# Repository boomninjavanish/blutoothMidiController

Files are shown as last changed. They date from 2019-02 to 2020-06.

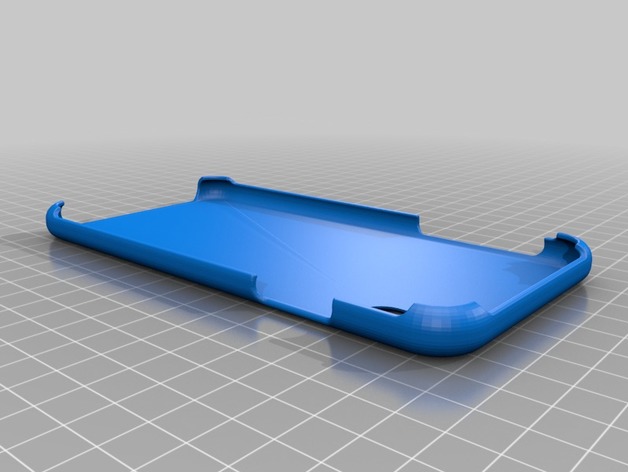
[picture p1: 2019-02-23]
case/iPhone_XS_Max_Case/images/488d43eb5ca74e51e7094f4cfa3dc460_preview_featured.jpg

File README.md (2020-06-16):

# portaMid
portaMid without phone docked

[Click to view video of portaMid in use.](https://vimeo.com/428870643)

[Click here to download the manual.](https://github.com/boomninjavanish/portaMid/raw/master/PortaMidUserManual.pdf)

The portaMid keyboard is a MIDI keyboard that works over the Bluetooth Low Energy (BLE) protocol which allows one to control music apps on any  Apple iOS device. The device contains a 500 mAh lithium polymer rechargeable battery which lasts for many hours of use. 

The one octave of piano style keys are soft to the touch but contain tactile feedback so that the user knows when the key has been pressed. Utilizing the octave  keys, the user may lower or raise the octave in which the piano-style keys play. The LED represents the octave selection via different color output.

A removable phone mount allows for use on the go for different sizes of iPhone. In fact, every iPhone since the 4S is supported by the device. Most music apps support MIDI over BLE natively and connect to the portaMid with no configuration required: just connect and use. An example of set-up with the GarageBand app may be found in the user manual.

## Motivation
I chose to create a portable MIDI controller that will allow one to dock a phone and use like a gaming controller. Often, I create music on train trips using my phone and hate inputting notes on the tiny keyboards presented on screen.

## Creation
### Board
A circuit board was designed using KiCAD and is centered around the Adafruit Feather 32u4 Bluefruit LE development microcontroller. The PCB design may be sent to a company such as OSH Park or PCB Way to be printed. The following is a bill of materials for the project (sans circuit board and case):

QTY | Part
---- | ------
1 | Adafruit Feather 32u4 Bluefruit LE Microcontroller
1 | Microchip MCP2307 I2C I/O expander (SPDIP)
1 | Adafruit NeoPixel Through-Hole 5mm LED
13 | 12mm tactile switches
3 |  5mm tactile switches
1 | 100nF ceramic capacitor
1 | 2mm DPDT surface mounted slide switch (DigiKey PN: 401-2002-1-ND)
1 | 1K SMD 1206 resistor
2 | 4.7K SMD 1206 resistor
1 | 3.7V/500mAh Lithium Ion Polymer Battery with 2-pin JST-PH connector

### Case
The final case was modeled in Fusion 360 and was designed to accept an existing phone mount that was found in [Thingiverse](https://www.thingiverse.com/thing:1313336). In order to ensure that the dimensions were correct, the board was exported from KiCAD as a STEP file. Other components such as switches, USB ports, and LEDs were imported into Fusion from a website called [GrabCAD](https://grabcad.com). This website is a community website similar to Thingiverse, but contains mostly engineering components. 

I printed the buttons in NinjaFlex 85A TPU,  which leaves the buttons tactile but feeling soft and reduces noise. The phone clamp connects to the case utilizing a ball joint which allows the keyboard to be used without the phone attached.

The side of the case contains an indentation that allows a USB micro cable to be plugged into the Adafruit feather for charging. The charging LED is visible through one hole near the port and a programmable LED is visible through another.

## User Feedback
For testing, the portaMid was given to two people for a week each. The following is the feedback from the first person:

>*I love the PortaMid!! As a musician who uses midi for all of my projects, it’s so convenient to be able to have an external midi controller. Especially because it’s so portable! I can easily fit it into my purse or backpack and use it wherever I go, train, bus, or at home. I also really love the design, the PortaMid looks as fun as it is to use. The buttons are accessible and labeled to help easily find the functions. I can’t wait to have a PortaMid of my own!*

The second person had the following to say:
>- *Good size to hold*
>- *Clear and simple user manual*
>- *LOVE the color change for different octaves- that was very useful*
>- *Bluetooth easy to set up*
>- *It only took me 10-15 min to get the hang of it and start playing melodies*
>- *I was really excited about the product, and it was more fun to use than I thought it would be*
>- *Thank you for letting me test it!*

## Improvements and Future Work
Going forward, further refinements to the device will be made. For example, it would be nice to have buttons that have the tactile feeling but are less difficult to press and create less noise. Research needs to be done on what could replace the standard tactile buttons with something that is better. In addition, it would be nice to have some velocity sensitive keys for playing more than one dynamic.

In addition, I will need to create a circuit that can poll the battery level at intervals in order to indicate the current charge level or if the battery is dying.

The stand could use a wing-nut to allow the user to adjust the tension so as to keep the unit in the proper position when in use. Also, it would allow for ease of removing the stand entirely.

While using the product, I found myself gripping the device like a game-pad. I had the thought of incorporating shoulder buttons which could be used for modulation, pitch bend, after-touch pressure, etc. 

I envision an entire line of these being made with different properties. For example it would be nice to have a version that mimics the Moog style ribbons, or another version that is a mini sequencer. It would only take finding different sensors or button layouts and incorporating them into the current design for a completely different type of interface.

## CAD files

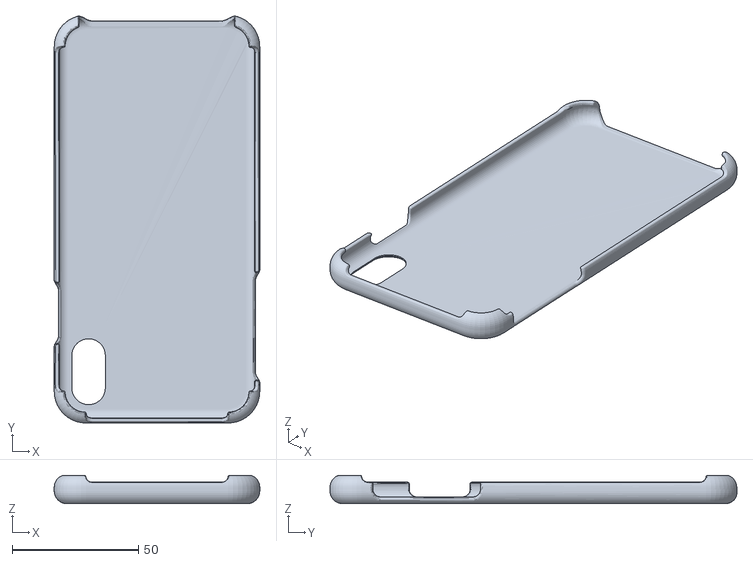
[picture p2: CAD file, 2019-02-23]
case/iPhone_XS_Max_Case/files/iphone-xs-max-case.stl
81.4 x 161.2 x 11.2

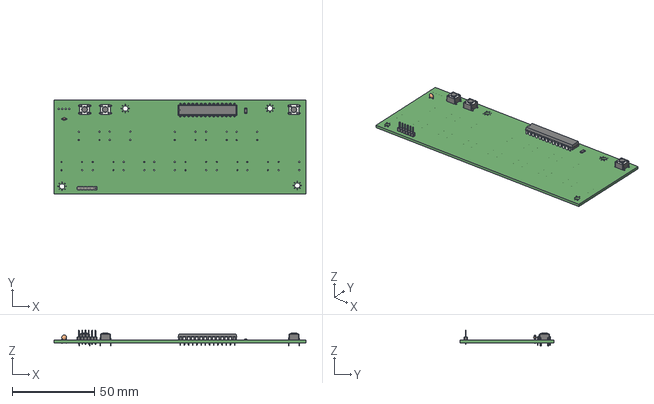
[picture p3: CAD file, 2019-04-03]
schematic/bluetoothMidiController/bluetoothMidiController.step
152.9 x 57.2 x 9.50 mm

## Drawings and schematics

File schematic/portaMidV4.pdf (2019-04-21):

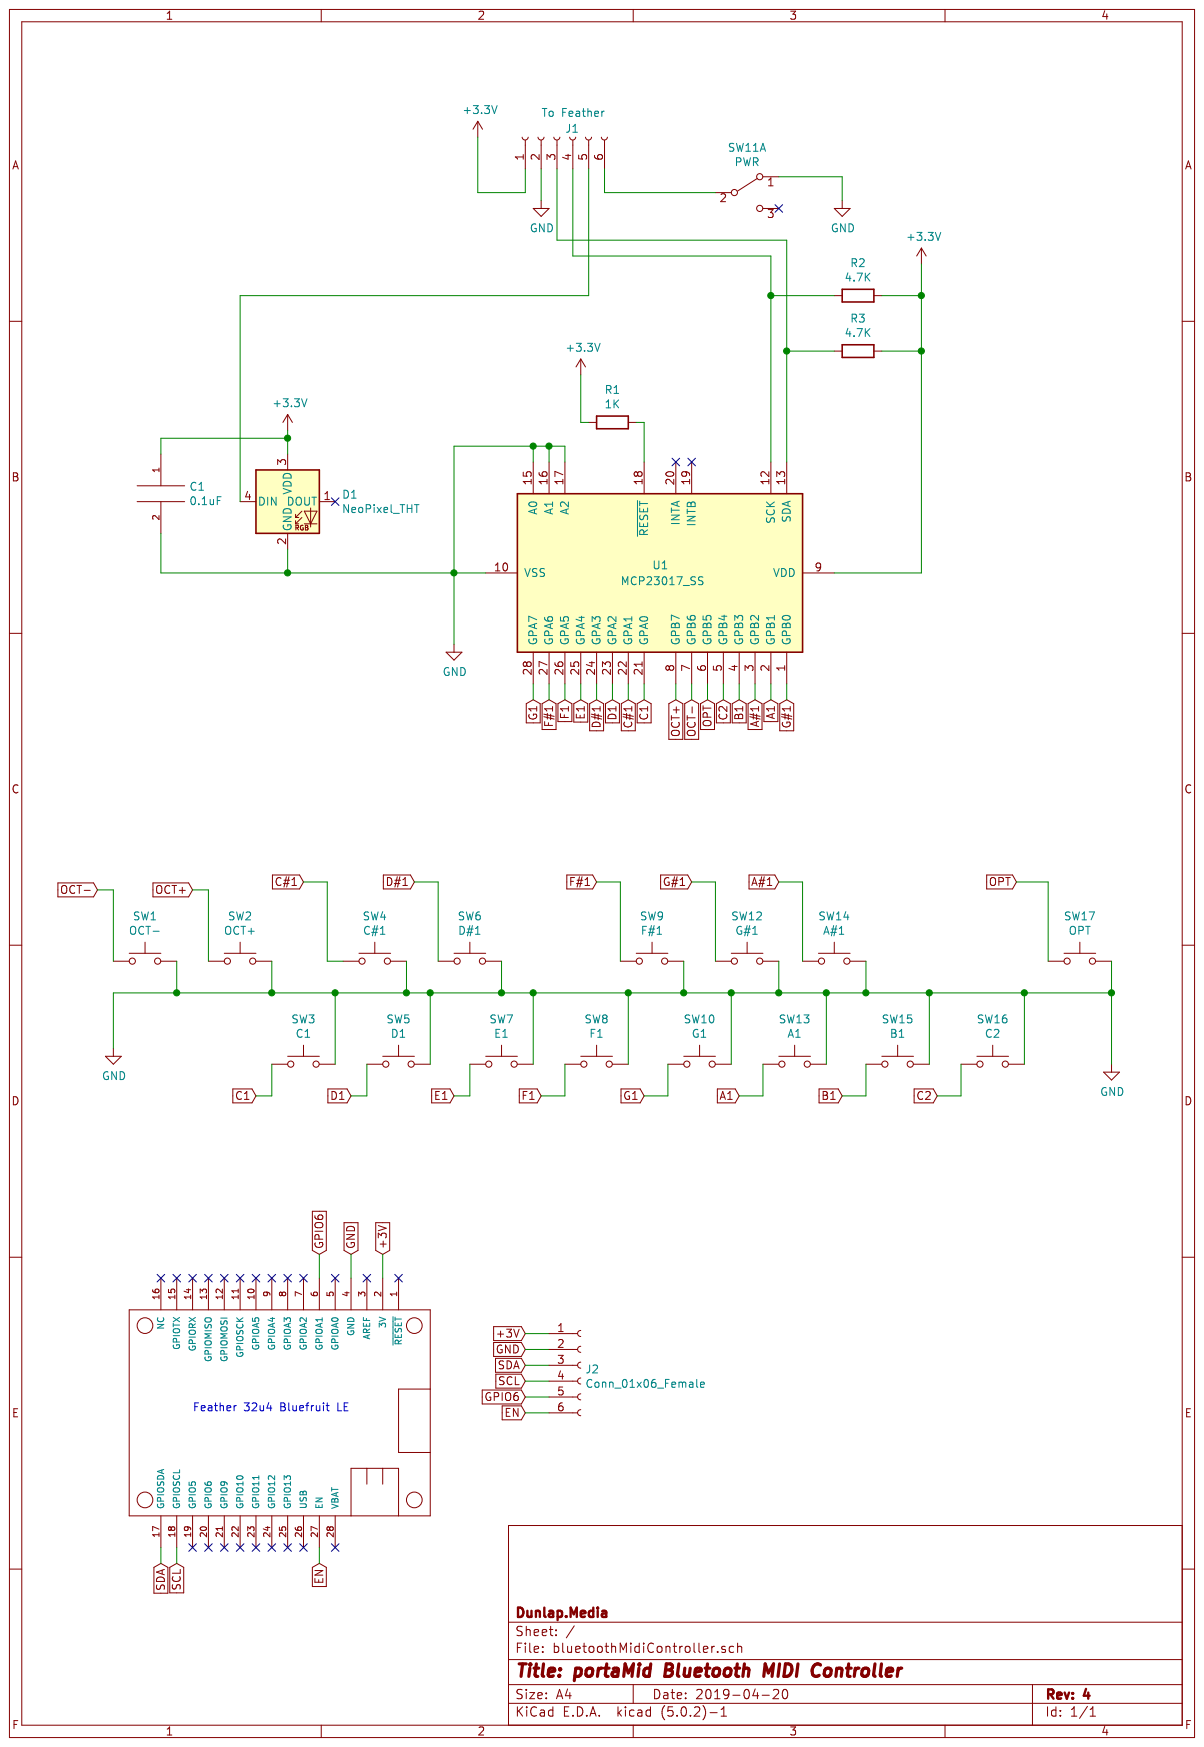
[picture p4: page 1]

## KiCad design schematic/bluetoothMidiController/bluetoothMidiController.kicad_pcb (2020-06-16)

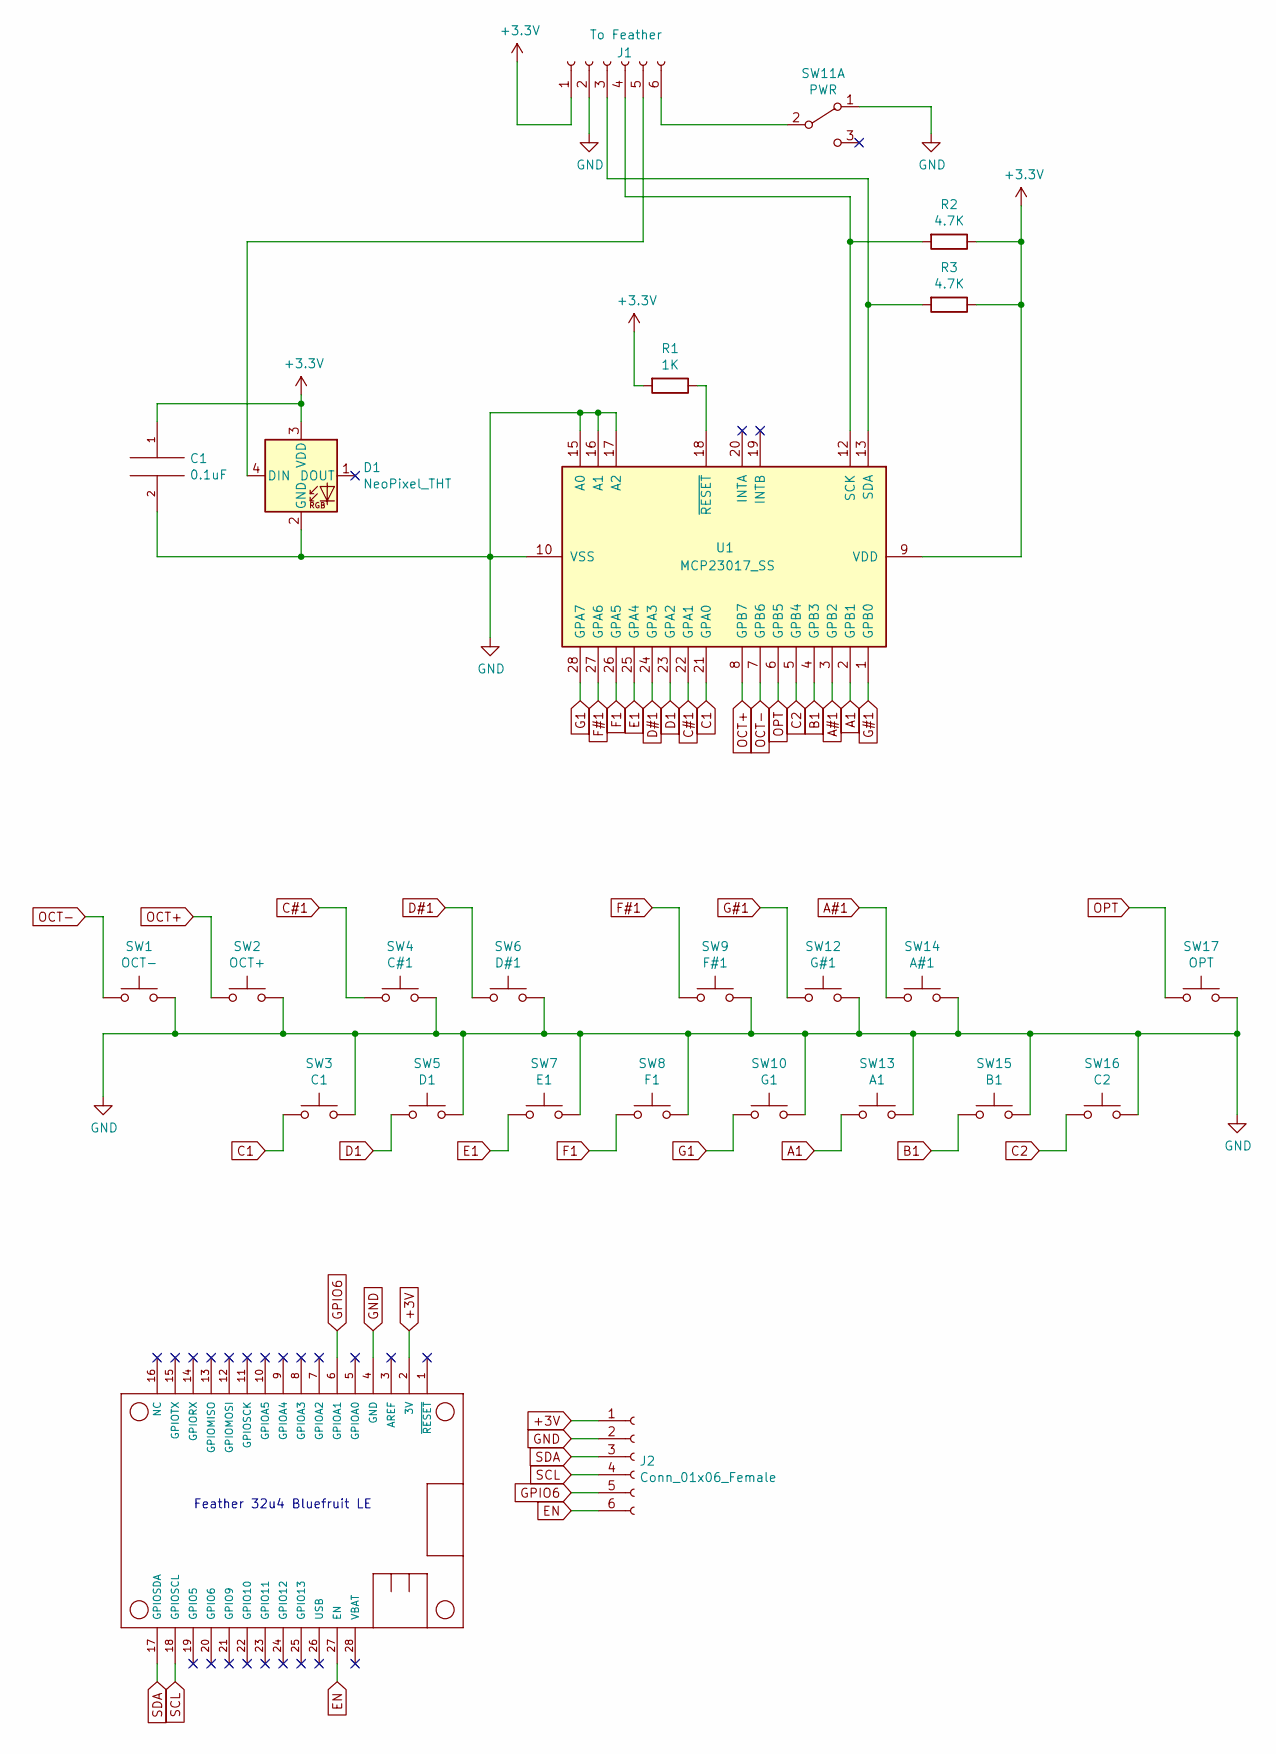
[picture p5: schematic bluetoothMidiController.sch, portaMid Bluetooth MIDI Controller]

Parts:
C1: 0.1uF; C_Disc_D3.0mm_W1.6mm_P2.50mm
D1: NeoPixel_THT; LED_D5.0mm-4_RGB_Wide_Pins
J1: To Feather; SolderWire-0.5sqmm_1x06_P4.8mm_D0.9mm_OD2.3mm
J2: Conn_01x06_Female
MS1: FEATHERWING
R1: 1K; R_1206_3216Metric_Pad1.42x1.75mm_HandSolder
R2, R3: 4.7K; R_1206_3216Metric_Pad1.42x1.75mm_HandSolder
SW1: OCT-; SW_PUSH_6mm
SW2: OCT+; SW_PUSH_6mm
SW3: C1; SW_PUSH-12mm
SW4: C#1; SW_PUSH-12mm
SW5: D1; SW_PUSH-12mm
SW6: D#1; SW_PUSH-12mm
SW7: E1; SW_PUSH-12mm
SW8: F1; SW_PUSH-12mm
SW9: F#1; SW_PUSH-12mm
SW10: G1; SW_PUSH-12mm
SW11: PWR; SW_SMD_DPDT_JS202011SCQN
SW12: G#1; SW_PUSH-12mm
SW13: A1; SW_PUSH-12mm
SW14: A#1; SW_PUSH-12mm
SW15: B1; SW_PUSH-12mm
SW16: C2; SW_PUSH-12mm
SW17: OPT; SW_PUSH_6mm
U1: MCP23017_SS; DIP-28_W7.62mm

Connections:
+3V3: C1.1, D1.3 (VDD), J1.1, R1.2, R2.1, R3.1, U1.9 (VDD)
A1: SW13.1, U1.2 (GPB1)
A#1: SW14.1, U1.3 (GPB2)
B1: SW15.1, U1.4 (GPB3)
C1: SW3.1, U1.21 (GPA0)
C2: SW16.1, U1.5 (GPB4)
C#1: SW4.1, U1.22 (GPA1)
D1: SW5.1, U1.23 (GPA2)
D#1: SW6.1, U1.24 (GPA3)
E1: SW7.1, U1.25 (GPA4)
F1: SW8.1, U1.26 (GPA5)
F#1: SW9.1, U1.27 (GPA6)
G1: SW10.1, U1.28 (GPA7)
G#1: SW12.1, U1.1 (GPB0)
GND: C1.2, D1.2 (GND), J1.2, SW1.2, SW2.2, SW3.2, SW4.2, SW5.2, SW6.2, SW7.2, SW8.2, SW9.2, SW10.2, SW11.1 (A), SW12.2, SW13.2, SW14.2, SW15.2, SW16.2, SW17.2, U1.10 (VSS), U1.15 (A0), U1.16 (A1), U1.17 (A2)
unnamed: D1.4 (DIN), J1.5
unnamed: J1.3, R3.2, U1.13 (SDA)
unnamed: J1.4, R2.2, U1.12 (SCK)
unnamed: J1.6, SW11.2 (B)
unnamed: J2.1, MS1.2 (3V)
unnamed: J2.2, MS1.4 (GND)
unnamed: J2.3, MS1.17 (GPIOSDA)
unnamed: J2.4, MS1.18 (GPIOSCL)
unnamed: J2.5, MS1.6 (GPIOA1)
unnamed: J2.6, MS1.27 (EN)
unnamed: R1.1, U1.18 (~RESET~)
OCT+: SW2.1, U1.8 (GPB7)
OCT-: SW1.1, U1.7 (GPB6)
OPT: SW17.1, U1.6 (GPB5)

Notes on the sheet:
Feather 32u4 Bluefruit LE

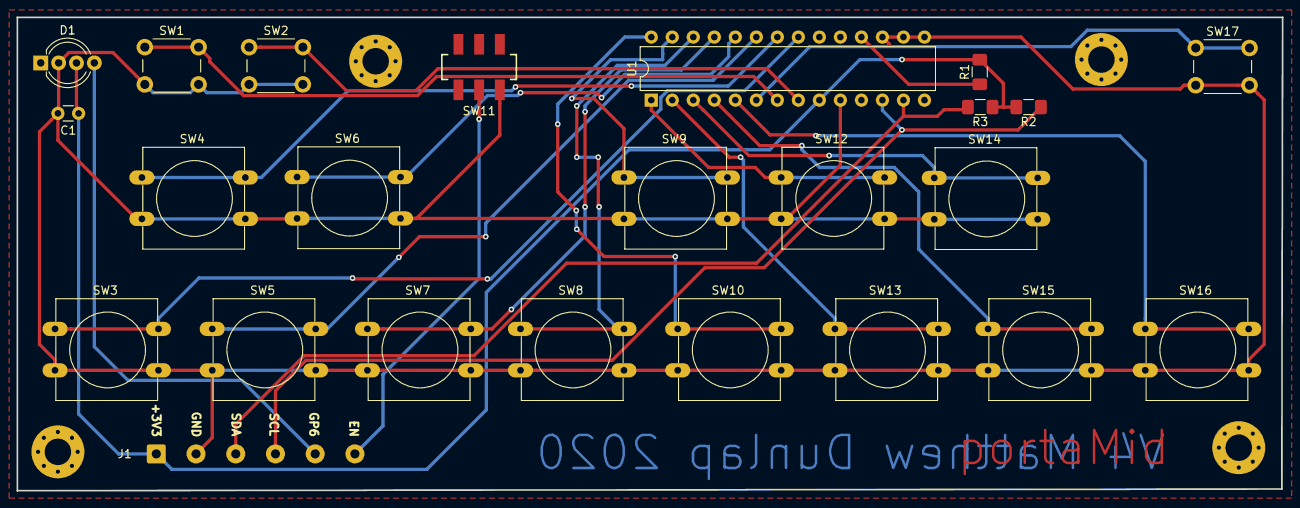
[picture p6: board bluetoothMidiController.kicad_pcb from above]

Board: 2 copper layers, 152.9 x 57.2 mm, 24 parts (0 on the bottom side), 23 nets.

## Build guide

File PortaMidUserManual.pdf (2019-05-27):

# portaMid

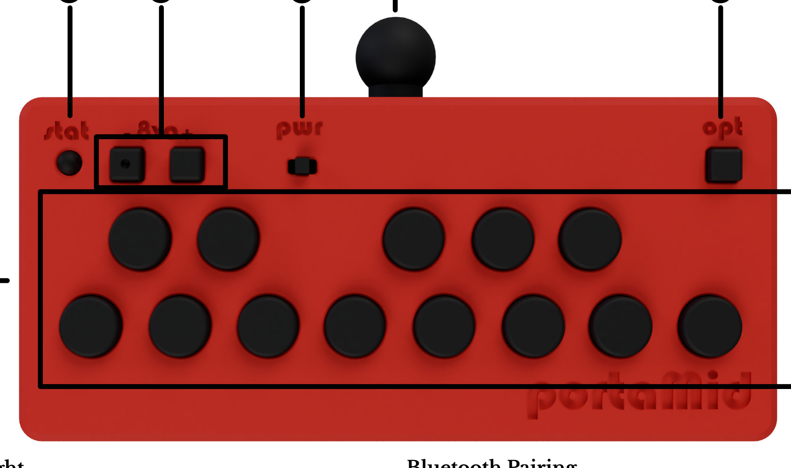
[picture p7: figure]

Status Light
Blinking Blue:
Bluetooth is ready for pairing Solid Color:
Ready for input. Color indicates which octave is selected.
No Light:
Device is turned off.
Octave Selection
Changes the octave that is played by the keyboard
Power Switch
Switches the power on the unit on or off

Phone Mount Connector
Mates with phone mounting device. Option Button
Unused at this time.
Keyboard
Press to send MIDI notes over bluetooth. USB Charging
Connect to charge device. Amber light near connector idicates that device is charging.

# User Manual

Bluetooth Pairing

When the device is first turned on, the status light will blink blue to indicate it is ready for pairing. Use the following instructions to pair with Garageband on iOS. Note that device will work on any app that supports Bluetooth MIDI on iOS and device only has to be paired each time it powered on.

1. Tap on the settings icon. (Looks like a wrench.)
2. Tap on the "Advanced" menu option.
3. Tap "Bluetooth MIDI Devices" menu option.
4. The device should appear as "portaMid" in the device list. Tap to connect.
5. Tap anywhere off of the menu to continue. Add an instrument in Garageband and enjoy. :)

### (on side)

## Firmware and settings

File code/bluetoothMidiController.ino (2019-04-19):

/*
 * bluetoothMidiController.ino
 * 2019 Matthew Dunlap
 * 
 * This project utilizes an Adafruit Feather 32u4 Bluefruit LE board (https://www.adafruit.com/product/2829)
 * to allow a user to input notes on a piano-style keyboard wirelessly to a mobile phone or tablet. 
 * Currently, as per my testing, MIDI over bluetooth LE is best supported on a device running iOS. However,
 * it is my hopes that this will change in the future.
 *
 */

#include <Arduino.h>
#include <SPI.h>
#include <SoftwareSerial.h>
#include "Adafruit_BLE.h"
#include "Adafruit_BluefruitLE_SPI.h"
#include "Adafruit_BluefruitLE_UART.h"
#include "Adafruit_BLEMIDI.h"
#include "Adafruit_MCP23017.h"
#include "BluefruitConfig.h"
#include "Bounce2mcp.h"
#include "Adafruit_NeoPixel.h"

// setup the bluetooth to only work with a certain firmware version
//  update the firmware via the Adafruit Bluefruit LE Connect app on iOS and Android
#define FACTORYRESET_ENABLE 1
#define MINIMUM_FIRMWARE_VERSION "0.7.0"

Adafruit_BluefruitLE_SPI ble(BLUEFRUIT_SPI_CS, BLUEFRUIT_SPI_IRQ, BLUEFRUIT_SPI_RST);

Adafruit_BLEMIDI midi(ble);

// define and init the MCP 23017 port expander objects
Adafruit_MCP23017 mcp;

//debouncer for the buttons
BounceMcp debouncer[16];

// track if a note is on for each button
bool buttonNoteOn[16];

// track if octave light has been turned on
bool lightOn = false;

// note and octave trackers; (OCTAVE * octaveMultiplier) + note = note in correct octave
const int OCTAVE = 12;

// track which octave we are in currently
int octaveMultiplier = 5;

// delay time in milliseconds after sending MIDI message
const int DELAY_TIME = 0;

// NeoPixel Vars
const int NEOPIXEL_PIN = 6;
Adafruit_NeoPixel pixel(1, NEOPIXEL_PIN, NEO_RGB + NEO_KHZ800);

// track milliseconds to blink led for bluetooth not connected
const long blinkInterval = 1000;
unsigned long previousMillis = 0;

// track if Bluetooth Module is connected
bool isConnected = false;


// error handeling
void error(const __FlashStringHelper*err) {
	Serial.println(err);
	while (1);
}

// when connected
void connected(void){
	isConnected = true;
	Serial.println(F(" CONNECTED!"));
	delay(1000);
}

// when disconnected
void disconnected(void){
	Serial.println("DISCONNECTED!");
	isConnected = false;
}

void setup() {
  Serial.begin(115200);

  // setup the built-in light
  pinMode(13, OUTPUT);

  // setup the neopixel
  pixel.begin();
  octaveColor(-1); // set to white
  pixel.setBrightness(10);
  pixel.show(); // initialize to brightness
  
  // setup the port expanders
  mcp.begin();
  
  /* Setup the buttons and LED
   *  
   *  All of the buttons are connected to both 23017 chips
   *    C1 - C2 are on mcp pins 0-12
   *    OCT - and + are on mcp pins 14 and 15 respectively
   *    An optional button is available on mcp pin 13
   *    The RBG LED pins are on the microcontroller: 
   *          Red = A0; Blue = A1; Green = A2
   */
  for (int i = 0; i < 16; i++){
    // initialize the button pressed tracker to false
    buttonNoteOn[i] = false;
    
    // setup pins as input
    mcp.pinMode(i, INPUT);
    mcp.pullUp(i,  HIGH);

    // setup debouncer if input
    debouncer[i] = BounceMcp();
    debouncer[i].attach(mcp, i, 5);   
  }
  
  // setup bluetooth
  if ( !ble.begin(VERBOSE_MODE) )
  {
    error(F("Couldn't find Bluefruit, make sure it's in CoMmanD mode & check wiring?"));
  }
  Serial.println( F("OK!") );

  if ( FACTORYRESET_ENABLE )
  {
    /* Perform a factory reset to make sure everything is in a known state */
    Serial.println(F("Performing a factory reset: "));
    if ( ! ble.factoryReset() ) {
      error(F("Couldn't factory reset"));
    }
    // set the Bluetooth name// set the Bluetooth name
    ble.sendCommandCheckOK("AT+GAPDEVNAME=portaMid");
  }
   ble.echo(false);

   Serial.println("Requesting Bluefruit info:");
  /* Print Bluefruit information */
  ble.info();
  
  /* Set BLE callbacks */
  ble.setConnectCallback(connected);
  ble.setDisconnectCallback(disconnected);

  Serial.println(F("Enable MIDI: "));
  if ( ! midi.begin(true) )
  {
    error(F("Could not enable MIDI"));
  }
  
  ble.verbose(false);
  
}

void loop() {

  // interval for each scanning ~ 500ms (non blocking)
  ble.update(1);

  // bail if not connected; turn light on for the first time
  if (! isConnected) {
    // blink LED blue to indicate bluetooth requires pairing
    unsigned long currentMillis = millis();

    if (currentMillis - previousMillis >= blinkInterval) {
      previousMillis = currentMillis;
      if (!lightOn){
        octaveColor(6); // turn light blue
        pixel.show();
        lightOn = true;      
      } else {
        pixel.clear();
        pixel.show();
        lightOn = false;
      }
    }
    
    
    
    return;
  } else {
    octaveColor(octaveMultiplier); // turn light on
  }
    
  
  pollButtons();

}

void pollButtons(){
  for (int i=0; i<16; i++) {  
      // calculate the current note
      int currentNote = (OCTAVE * octaveMultiplier) + i;
  
      // read the current button
      debouncer[i].update();
      
      // check if the button being pressed is an octave button
      if (i == 14 && debouncer[i].fell()){
        // lower an octave
        if (octaveMultiplier > 1) {
          octaveMultiplier -= 1;
          octaveColor(octaveMultiplier);
        }
      } else if(i == 15 && debouncer[i].fell()){
        // raise an octave
        if (octaveMultiplier < 8) {
          octaveMultiplier += 1;
          octaveColor(octaveMultiplier);
        }
      } else if( i < 14 ){ // button is piano key
        int buttonState = debouncer[i].read();
        if ( buttonState == LOW && buttonNoteOn[i] == false){  
          // send the note on 
          midi.send(0x90, currentNote, 0x64);
          buttonNoteOn[i] = true;

          digitalWrite(13, HIGH); // led on
          
          delay(DELAY_TIME);
          Serial.print("Note: ");
          Serial.println(currentNote);
        } else if (buttonState == HIGH && buttonNoteOn[i] == true) {
          // send note off
          midi.send(0x80, currentNote, 0x64);
          buttonNoteOn[i] = false;
    
          digitalWrite(13, LOW); // led off
        }
      } 
   }
}

void octaveColor(int octaveMultiplier){
  switch (octaveMultiplier){
    case 0 :
       pixel.clear(); // off
    
    case 1 :
      pixel.setPixelColor(0, 255, 0, 0); // red
      break;

    case 2 :
      pixel.setPixelColor(0, 255, 127, 0); // orange
      break;
      
    case 3 :
      pixel.setPixelColor(0, 255, 255, 0); // yellow
      break;
      
    case 4 : 
      pixel.setPixelColor(0, 0, 230, 0); // green
      break;
      
    case 5 : 
      pixel.setPixelColor(0, 0, 255, 255); // aqua
      break;

    case 6 : 
      pixel.setPixelColor(0, 0, 42, 255); // blue
      break;

    case 7 :
      pixel.setPixelColor(0, 221, 51, 255); // purple
      break;

    case 8: 
      pixel.setPixelColor(0, 255, 25, 255); // fuchsia
      break;

    default :
      pixel.setPixelColor(0, 255, 255, 255); // white
    
  }

  pixel.show();
}

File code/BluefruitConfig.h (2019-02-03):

// COMMON SETTINGS
// ----------------------------------------------------------------------------------------------
// These settings are used in both SW UART, HW UART and SPI mode
// ----------------------------------------------------------------------------------------------
#define BUFSIZE                        128   // Size of the read buffer for incoming data
#define VERBOSE_MODE                   true  // If set to 'true' enables debug output


// SOFTWARE UART SETTINGS
// ----------------------------------------------------------------------------------------------
// The following macros declare the pins that will be used for 'SW' serial.
// You should use this option if you are connecting the UART Friend to an UNO
// ----------------------------------------------------------------------------------------------
#define BLUEFRUIT_SWUART_RXD_PIN       9    // Required for software serial!
#define BLUEFRUIT_SWUART_TXD_PIN       10   // Required for software serial!
#define BLUEFRUIT_UART_CTS_PIN         11   // Required for software serial!
#define BLUEFRUIT_UART_RTS_PIN         12   // Optional, set to -1 if unused


// HARDWARE UART SETTINGS
// ----------------------------------------------------------------------------------------------
// The following macros declare the HW serial port you are using. Uncomment
// this line if you are connecting the BLE to Leonardo/Micro or Flora
// ----------------------------------------------------------------------------------------------
#ifdef Serial1    // this makes it not complain on compilation if there's no Serial1
  #define BLUEFRUIT_HWSERIAL_NAME      Serial1
#endif


// SHARED UART SETTINGS
// ----------------------------------------------------------------------------------------------
// The following sets the optional Mode pin, its recommended but not required
// ----------------------------------------------------------------------------------------------
#define BLUEFRUIT_UART_MODE_PIN        -1    // Set to -1 if unused


// HARDWARE SPI SETTINGS
// ----------------------------------------------------------------------------------------------
// The following macros declare the pins to use for HW SPI communication.
// SCK, MISO and MOSI should be connected to the HW SPI pins on the Uno, etc.
// This should be used with nRF51822 based Bluefruit LE modules that use SPI.
// ----------------------------------------------------------------------------------------------
#define BLUEFRUIT_SPI_CS               8
#define BLUEFRUIT_SPI_IRQ              7
#define BLUEFRUIT_SPI_RST              6    // Optional but recommended, set to -1 if unused

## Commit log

2019-02-03 Initial Commit of Code and other files
    [midiKeyboard BOM.xlsx]
2019-02-10 Added schemtic and PCB design files.
    [bluetoothMidiController.kicad_pcb, bluetoothMidiController.sch]
2019-02-23 Added 3D printed case design
    [bluetoothMidiController.step, iphone-xs-max-case.stl]
2019-02-23 Added two MCP23017
    Changed the code so it now supports the two MCP23017 chips for I/O. Moved to a different Bounce2 library as a result. Some more work needs to be done to improve speed and reliability of the device. Code does not work right now.
    [bluetoothMidiController.ino]
2019-03-04 removed debouncerMCP
    Removed the debouncer in the hopes that the board will be more responsive.
    [bluetoothMidiController.kicad_pcb, bluetoothMidiController.sch, bluetoothMidiController.step]
2019-03-08 Reduced to one MCP23017 and Updated wiring on board
    I removed one MCP23017 because the keyboard is reducing in size and the other expander is no longer needed. Also, I discovered that I was wiring the board incorrectly and adjusted the code to reflect the change in hardware.
    [bluetoothMidiController.kicad_pcb, bluetoothMidiController.sch, bluetoothMidiController.step]
2019-03-08 Added RGB LED support; started version 2 of board
    [bluetoothMidiController.kicad_pcb, bluetoothMidiController.sch, bluetoothMidiController.step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]
2019-03-09 completed V2 of the PCB
    [bluetoothMidiController.kicad_pcb]
2019-04-03 Change Board to V3 for DIP version of MCP23017
    [bluetoothMidiController.kicad_pcb, bluetoothMidiController.sch, bluetoothMidiController.step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]
2019-04-19 Changed the RGB LED to a single 5mm Adafruit Neopixel
    [bluetoothMidiController.sch]
2019-04-21 Changed schematic to version 4
    Added pull-up resistors for MCP23017
    [bluetoothMidiController.kicad_pcb, bluetoothMidiController.sch, bluetoothMidiController.step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]
2020-06-14 cleaned up folders and added README.md
    [bluetoothMidiController.kicad_pcb, bluetoothMidiController.sch, bluetoothMidiController.step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]
2020-06-14 removed extraneous files
    [bluetoothMidiController.kicad_pcb, bluetoothMidiController.sch, bluetoothMidiController.step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]
2020-06-16 updated PCB to include two 4.7K resisters for I2C bus
    [bluetoothMidiController.kicad_pcb, bluetoothMidiController.sch]
2020-06-16 corrected number of 4.7K resistors
